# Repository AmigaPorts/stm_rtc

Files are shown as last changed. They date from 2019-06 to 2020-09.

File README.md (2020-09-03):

# STM32 emulator of msm6264b RTC for Amiga computers

This project aims to implement RTC replacement for classic Amiga computers.
Target uC was chosen to be as cheap as possible, easily available & RoHS-friendly.
This project may work on other computers, but it's not guaranteed.

If you made it work for other machine with some fix or without it,
tell me so by creating an issue!

## Build and flash

To build firmware, you'll need STM32CubeMX installed to generate required HAL stuff.
This way you can also easily port this project to other chips.

- Delete `build` folder if present in main repo directory.
- Delete `makefile` if present in main repo directory.
  For some reason STM32CubeMX doesn't regenerate it each time.
- Open stm_rtc_yourPartName.ioc in STM32CubeMX, then click `GENERATE CODE` button.
- After that, simply use generated makefile by writing:

``` sh
make OPT="-Ofast -std=c11 -Wpedantic -frename-registers" DEBUG=0
```

If you're on Windows and have MinGW installed, you may use `mingw32-make` instead.
This should generate firmware in `./build/stm_rtc.bin`.
I've used following GCC version:

``` plain
> arm-none-eabi-gcc --version
arm-none-eabi-gcc (GNU Tools for ARM Embedded Processors) 5.4.1 20160919 (release) [ARM/embedded-5-branch revision 240496]
```

To flash firmware into your STM you'll need `stm32flash` tool installed.
Required pinout is as follows:

``` plain
PA14 (TX) - USB-UART RX
PA15 (RX) - USB-UART TX
BOOT0     - 3v3 during programming, GND when run
RES       - 3v3 via 10k or any other resistor
```

You may need to drive RES for a short time to GND to reset device before programming.

Connect UART-USB dongle to your PC and type:

``` sh
stm32flash -R -w ./build/stm_rtc_stm32f031k4u.bin COM5
# or
stm32flash -R -w ./build/stm_rtc_stm32f030c6t.bin COM5
```

Of course replace COM5 with name of correct serial port.
You may use Realterm, Cutecom or whatever serial monitor you prefer to list them.

## How it works

TBD

## License

See each file for details.

- All ST code is under STMicroelectronics's license.
- MSM RTC emulation code found in `msm_rtc.c` and `msm_rtc.h` is licensed under [Mozilla Public License 2.0](LICENSE).

## TODO

- write
- add pinout compatibility with smaller stm32f0 packages
- port to  STM32F031C6T6
- PCB
- switch to LL generation for less footprint?
- compat with latest arm gcc?
- stm32f030 power saving code for even cheaper device?

## This worked on QFP48

``` asm
 147              	.L5:
 148 001c 0B69     		ldr	r3, [r1, #16]
 149 001e 1340     		ands	r3, r2
 150 0020 FCD1     		bne	.L5
 151 0022 3869     		ldr	r0, [r7, #16]
 152 0024 050A     		lsrs	r5, r0, #8
 153 0026 3540     		ands	r5, r6
 154 0028 A800     		lsls	r0, r5, #2
 155 002a 6546     		mov	r5, ip
 156 002c 2858     		ldr	r0, [r5, r0]
 157 002e 4546     		mov	r5, r8
 158 0030 6061     		str	r0, [r4, #20]
 159 0032 2560     		str	r5, [r4]
 160 0034 2360     		str	r3, [r4]
 161 0036 F1E7     		b	.L5
```

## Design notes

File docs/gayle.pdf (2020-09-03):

## ’ Specification GAYLE

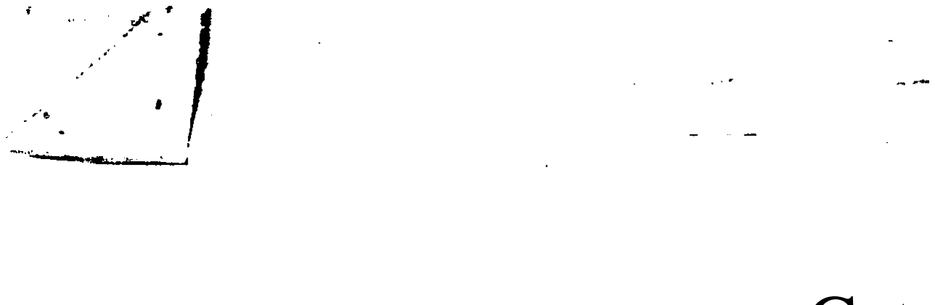
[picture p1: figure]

## Gate array for A30O/A500+ /w 0 /N APoo

1 .O DESCRIPTION

GAYLE is a gate array IC used in the A’300 and related systems. It is packaged in an 84 pin plastic leaded chip carrier (PLCC) whose pinout is shown below. GAYLE is capable of operating a 68000 based Amiga computer with theECS chipset, and a processor clock speed of 7.16 Mhz. GAYLE provides the following functions:

- Address decoding and timing for system ROM
- Address decoding and timing for optional flash ROM
- Address decoding and timing for chip RAM
- Address decoding and timing for chip registers
- Address decoding and timing for 8520’s (CIA’s)
- Address decoding and timing for real time clock (RTC)
- Address decoding and timing for Credit card connector
- Address decoding and timing for IDE hard disk drive
- Address decoding and timing for COM200020 ArcNet chip
- Generation of ECLK clock signal
- Data buffer control
- System RESET logic
- Floppy glue

[ Insert pinout here )

1.1 CONFIGURATION
The device shall be configured as a standard 54 pin plastic leaded chip carrier with external dimensions as shown in Figure XX-x. Refer to figure x-x for connection diagram.

1.2 SOURCES
Refer to Approved Vendor List.

1.3 PIN DESCRIPTIONS

1 | OUT
2 | OUT
3 | PWR
4 | TS
5 | OUT
6 | OUT
7 | OUT
8 | OUT
9 | OUT
10 | OUT
11 | OUT
12 | IN
13 | OUT
14 | OUT
15 | OUT
16 | OUT
17 | OUT
18 | OUT
19 | OUT
20 | PWR
21 | OUT
22 | IN
23 | IN
24 | PWR
25 | IN
26 | IN
27 | OC
28 | o c
29 | IN
30 | OUT
31 | OUT
32 | OUT
33 | IN
34 | IN
35 | IN
36 | IN
37 | TS
38 | IN
39 | o c
40 | o c
41 | IN
42 | IN
43 | IN
44 | IN
45 | PWR
46 | IN
47 | IN
48 | IN
49 | IN
50 | IN

PE12
PE5
Gndl
NOISE
CC-RESET
-CC-ENA
-CC-REG
-CC-CEL
-CC-CEU
E
FLAS H

### -mEJRQ

-DLCS(l)
DE-CW
-SPARE-CS
-INET-CS
-RTC-CS
-1OWR
-IORD
vcc 1
-ROMEN
C14M
CCK

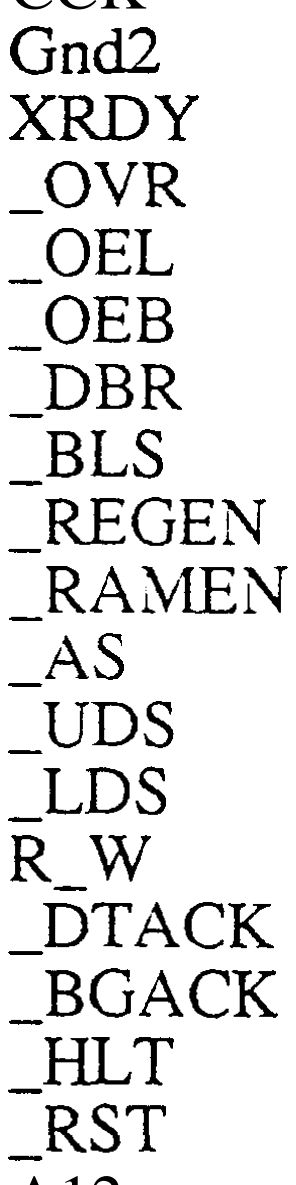
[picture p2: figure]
GIld.2 XRDY -0VR -0EL -0EB -DBR -BLS REGEN -RAMEN -AS -UDS -LDS R-W -DTACK -BGACK -HJJ- -RST

A12
Al3
A14
A15
Gnd3
A16
A17
Al8
A19
A20

Program Voltage 12V Enable Program Voltage 5V Enable
Ground
Digital Audio
Memory Card Reset
Memory Card Enable
Memory Card “Register” Space Memory Card Chip Enable Low byte Memory Card Chip Enable High byte CIA Phi 2
Flash Memory Chip Enable
IDE Drive Interrupt Request
IDE Drive Chip Select 1
IDE Drive Chip Select 2
Spare Chip Select
Network Controller Chip Select Real Time Clock Chip Select I/O Write Strobe
I/O Read Strobe
+5v
ROM Chip Enable
14 MHz C1ock In (master)
CCK Clock IN (sync)
Ground
Expansion Bus Wait
Expansion Bus Decode Override Chip->68000 Bus Buffer Enable 68000->Chip Bus Buffer Enable Agnus Chip Data Bus Required Agnus Chip Blitter Slowdown Agnus Chip Register Enable Agnus Chip RAM Enable
68000 Address Strobe
68000 Upper Data Strobe
68000 Lower Data Strobe
68000 Read/Write
68000 Data Transfer Acknowledge 68000 Bus Grand Acknowledge 68000 Halt
68000 Reset
68000 Address Bit 12
68000 Address Bit 13
68000 Address Bit 14
68000 Address Bit 15
Ground
68000 Address Bit 16
68000 Address Bit 17
68000 Address Bit 18
68000 Address Bit 19
68000 Address Bit 20
GAYLE Specification | July 10, 1991 | Page 2 of 17

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
A21 | 68000 Address Bit 21
A22 | 68000 Address Bit 22
A23 | 68000 Address Bit 23
D7 | 68000 Data Bit 7
D6 | 68000 Data Bit 6
D5 | 68000*Data Bit 5
D4 | 68000 Data Bit 4
D3 | 68000 Data Bit 3
D2 | 68000 Data Bit 2
Dl | 68000 Data Bit 1
DO | 68000 Data Bit 0
vcc2 | +5v
KBRESET DKWEB | Keyboard Reset In
DKWDB | Floppy Write Enable Out
Gnd4 | Floppy Write Data Out
| Ground
MTRON MTRX | Floppy Motor On Out
DKW E | Floppy Motor Out
-DKW-D | Floppy Write Enable In
MTR | Floppy Write Data In
-SEL | Floppy Motor In
-ODD-CIA | Floppy Select In
-EVEN-CIA | CIA Odd Chip Select
| CIA Even Chip Select

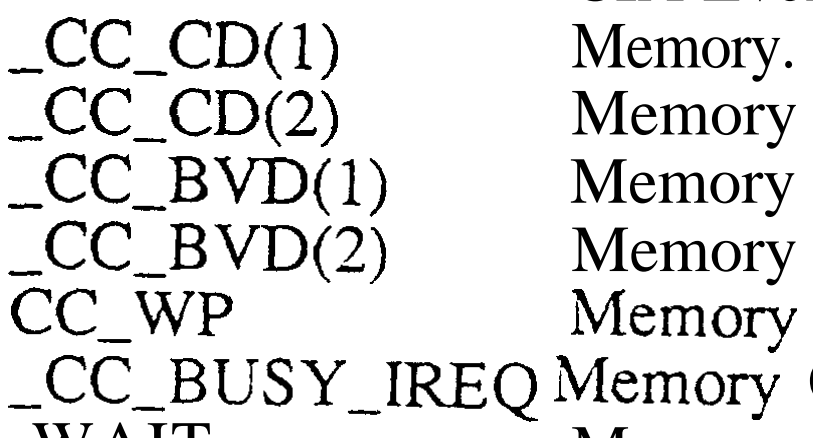
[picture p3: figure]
-CCCW) _Cccw2) -CCBWl) -CC_BVD(2) cc-WP

| Memory. Card Card Detect 1
| Memory Card Card Detect 2
| Memory Card Battery Voltage Detect 1
| Memory Card Battery Voltage Detect 2
| iMemory Card Write Protect
-CC-BUSY-IREQ LMemory Card Busy/Interrupt Request
-WAIT -BERR | Memory Card Wait
-INT6 | Bus Error Interrupt Request
-1NT2 | High Priority Interrupt Request
| Low Priority Interrupt Request
GAYLE Specification | Juiy 10, 1991 | Page 3 of 17

2.0 SYSTEM ROM

The onboard ROMs are selected in the address range from $OASOOOO to $OB7FFFF, $OEOOOOO to $OE7FFFF, and $OFSOOOO to $OFFFFFF. The ROMs are also selected in the range from $0000000 to $OlFFFFF when the internal overlay signal (OVL) is high (this allows the RESET vectors to be contained in the ROMs). The internal OVL signal becomes asserted at reset, and negates on the first write to CIA1 (address range of $BFDOOO to $BFDFFF.

2.1 ROM Timing

ROM timing is shown below:

## ROM Timing

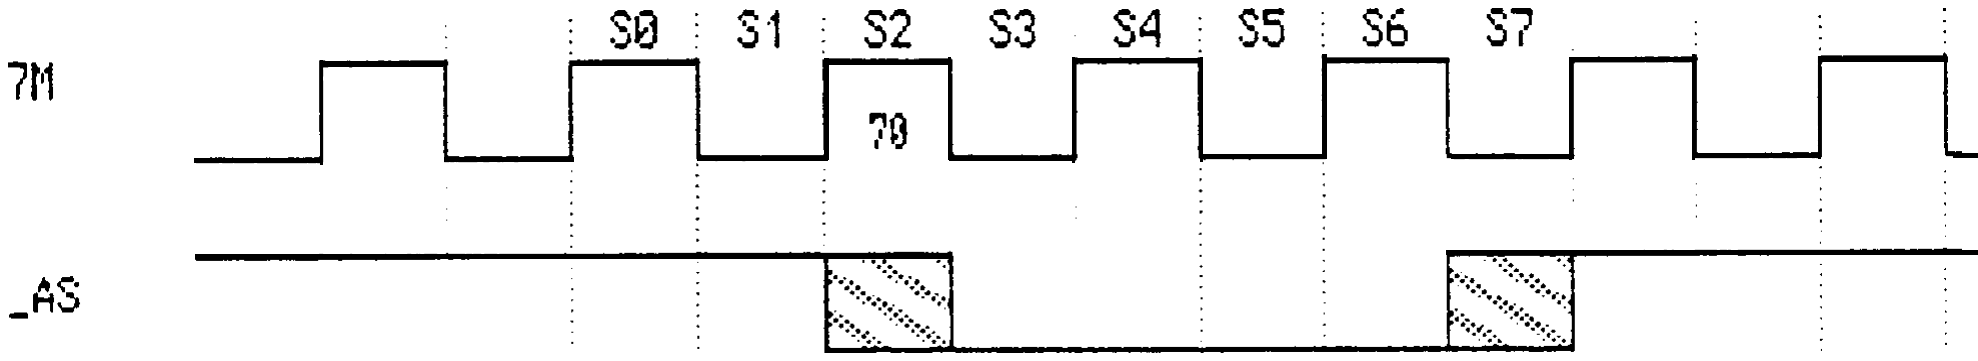
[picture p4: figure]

-ROM
I

JOH is a pure~address &code

: :

3.0 FLASH ROM
There is provision for an optional flash ROM device. The intent is that this is a possible replacement for a floppy disk drive in an extremely low end variant of the A300. The enable for the flash rom is called -FLASH-CE, and is active in the address range from $OAOOOOO to $OA7FFFF. This output is enabled when the proper data strobe is asserted, and the address is in range. Generation of -DTACK is identical to that for system ROa accesses.

3.0 CHIP RAM

Chip RAM cycles are generated during accesses to locations $0000000 to $0200000. When the internal OVL signal is asserted, ROM appears in this space instead of chip RAlM (see section on ROM for further information on OVL).

3.1 Chip RAM Timing

Timing for chip RAM cycles is given in the timing section of the Chip Register discussion (section 4.1). All timings given are equally valid for either chip registers or chip RAM.

4.0 CHIP REGISTERS

The chip registers are selected in the range from $ODFFOOO to $ODFFlFF. Chip registers show up in user and supervisor data space.

4.1 Chip RAM and Register Timing

Timing is given on the following page. Note that timimng for chip RAM accesses is identical. A wait state is inserted when the access is from a DMA device.

## Chip RAM and Register Timing

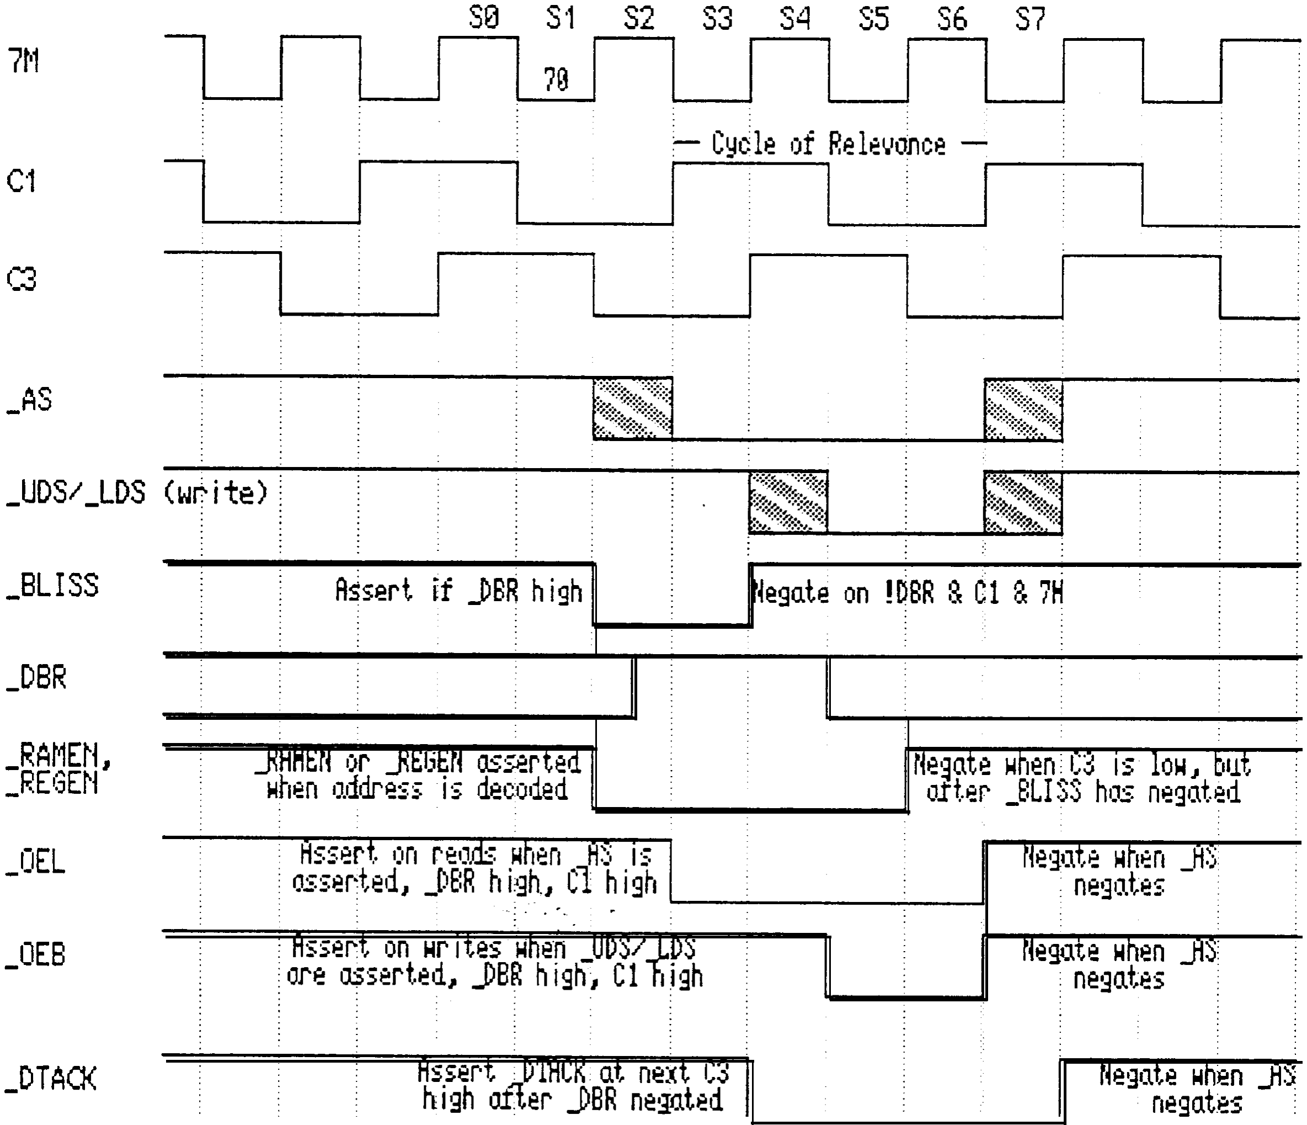
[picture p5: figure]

5.0 CIA’

The 8520 CIA’s are selected in the address range from $OBFOOOO to $OBFFFFF. ODD-CIA responds to addresses in this range in which address line 12 is low, with data appearing at odd addresses. The standard location to use in accesssing ODD-CIA is from $OBFEOOO to $OBFEFFF. EVEN-CIA responds to addresses from $OBFOOOO to $OBFFFFF in which address line 13 is low, with data appearing at even addresses. The standard location to use for accessing this CIA is from $OBFDOOO to $OBFDFFF.

5.1 CIA timing

GAYLE provides synchronization of the processor to CIA accesses as well as generation of the E clock signal. Timing is shown below:

## CIA Timing

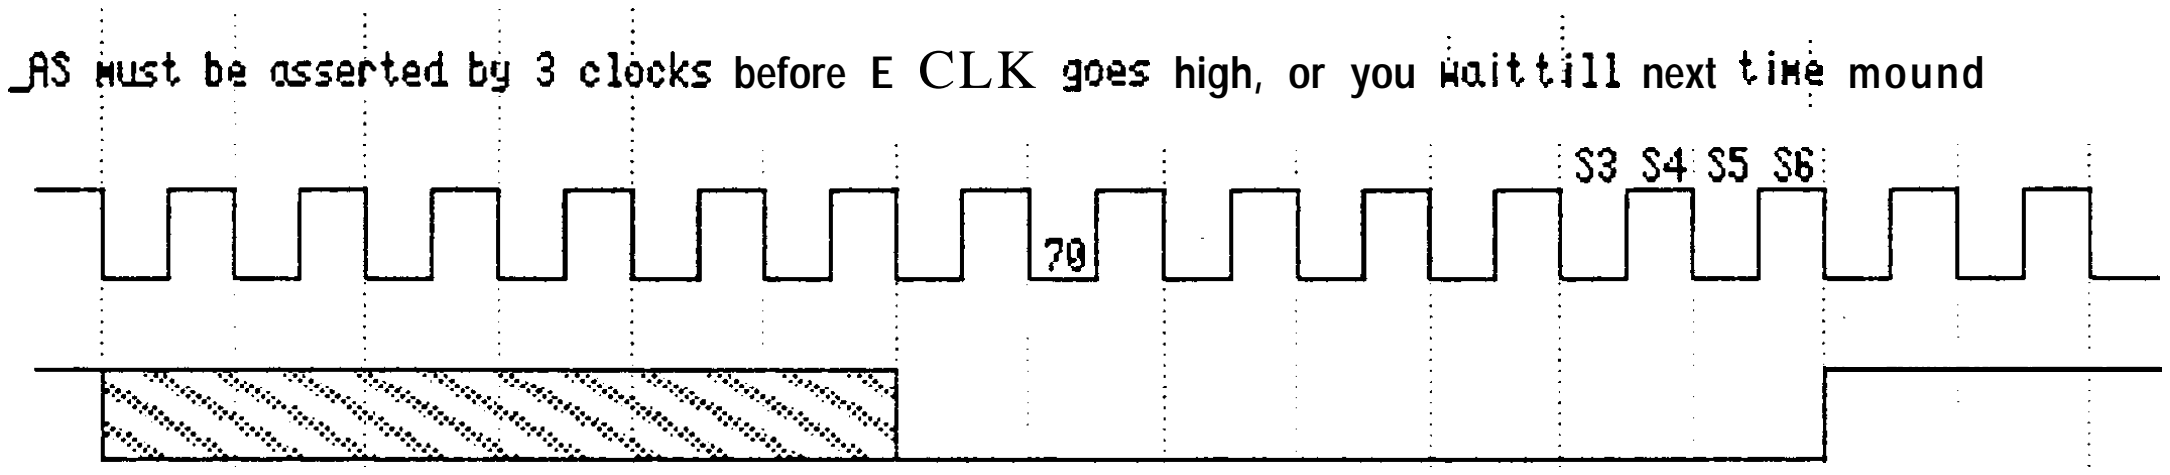
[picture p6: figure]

:ks before E CLK goes high, or you bait till next tin! mound

E CLK is lou foe E clocks . . . | then h igh for 4

Ass& 2 clocks before E CLK goes high

i JXACK ass&cd 2.5 clocks after E CLK h iih

6.0 REAL-TIME CLOCK

The real-time clock (RTC) is selected in the address range from $ODCOOOO to $ODCFFF. The RTC appears in both user and supervisor spaces.

6.1 RTC Timing

The real-time clock timing is based on the Ricoh RP5COl real-time clock chip. GAYLE’s timing to the RTC is shown below:

## Real Time Clock Timing

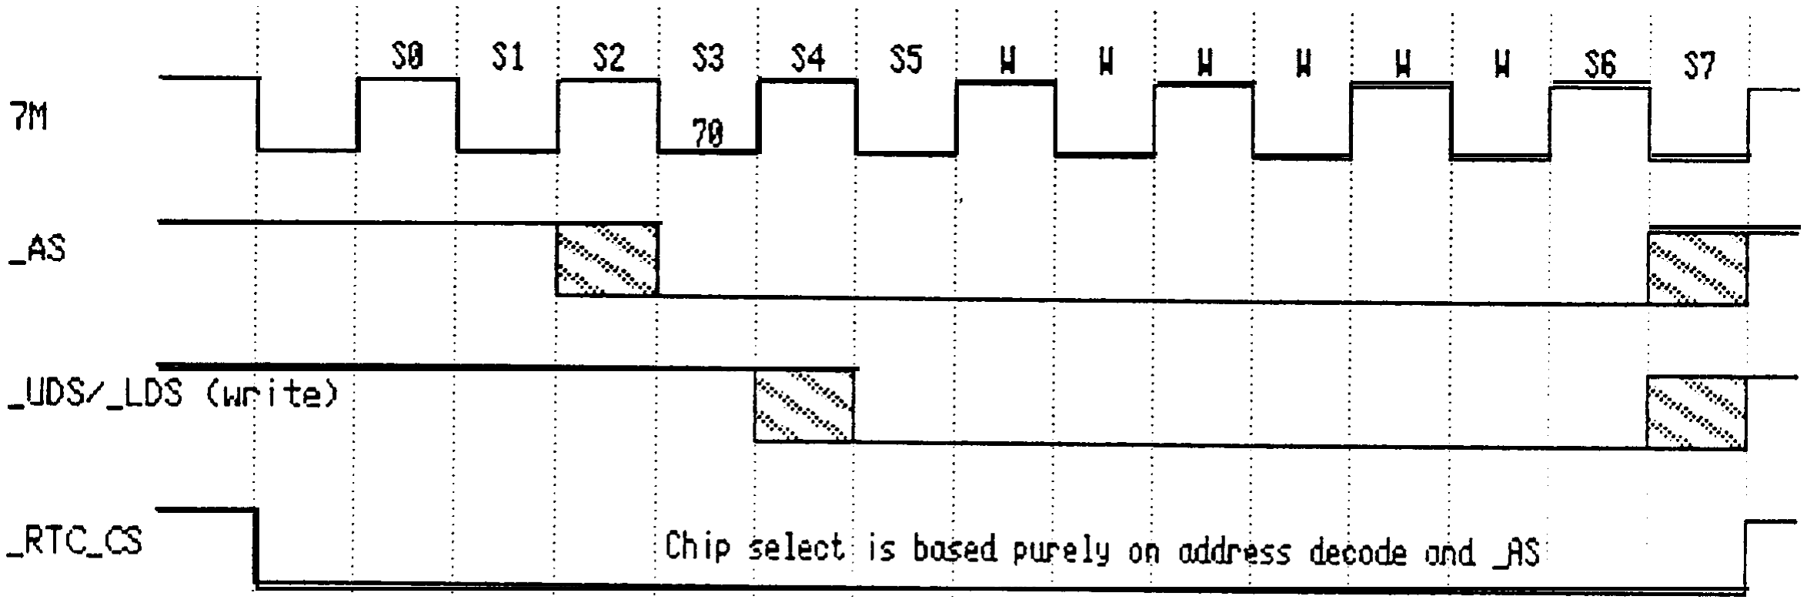
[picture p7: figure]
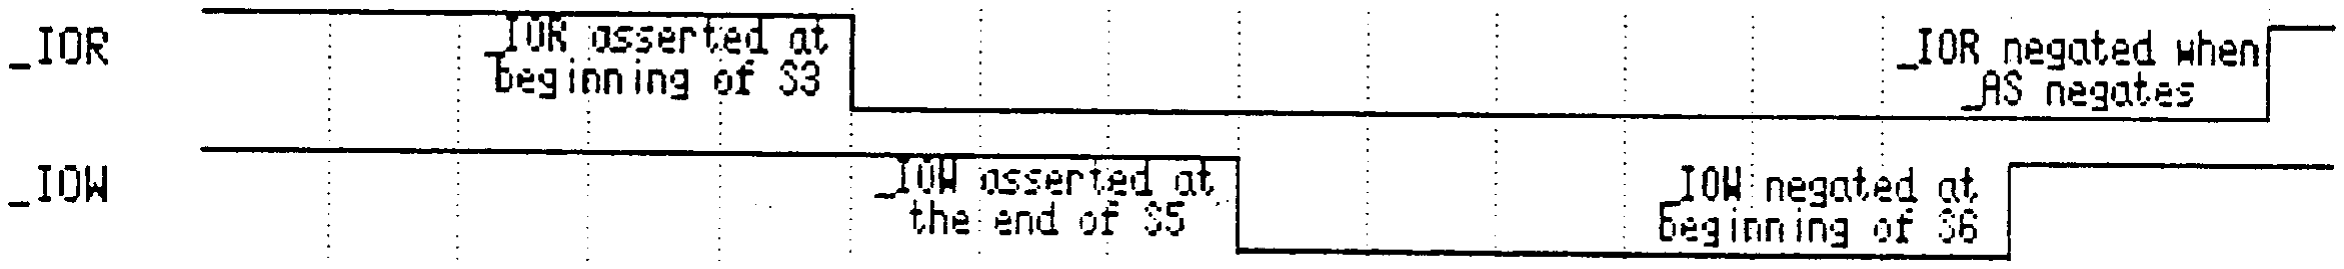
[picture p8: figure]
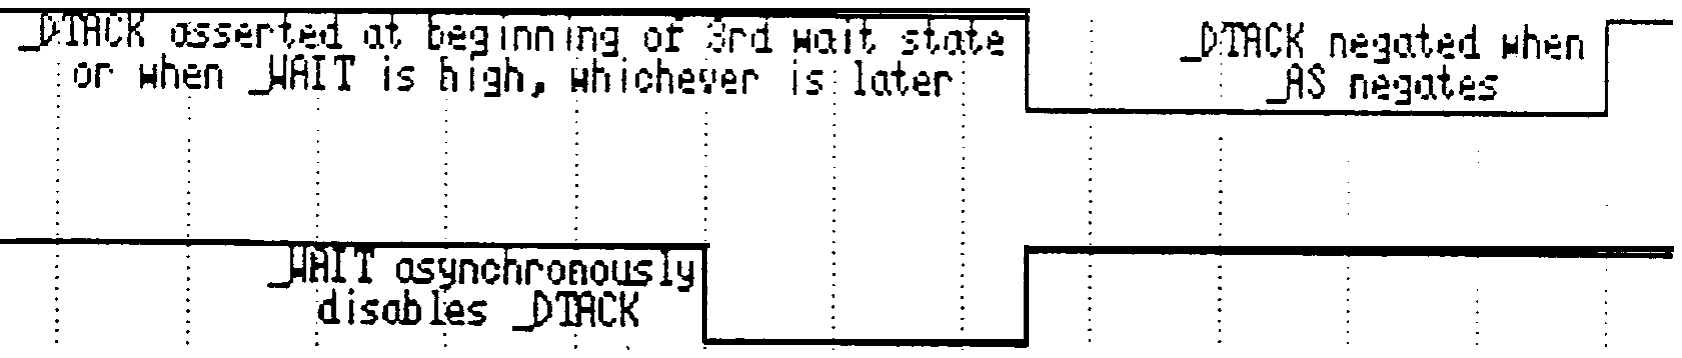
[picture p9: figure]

-WAIT

7.0 IDE HARD DRIVE

The IDE (AT) hard drive requires two mutually exclusive chip selects. Please see the chart below for address range in which each is active.
valid for IDE hard drives during these cycles.

The -1OW and -1OR signals have timing that is

Data register accesses CZ.P
control registers are

be performed faster than control register accesses. Accesses to the 1;dlled
accesses”.

“8 bit accesses” while those to the data register are called “16 bit Show: oelow is a table that gives the chip select and access speed versus address range.

4u+ | Al3 Al 2
b | 0 | | Address Range
| | 0 | $ODAOOOO to SODAOFFF
0 | 0 | 1 | $ODAlOOO to $ODAiFFF
0 | 1 | 0 | $ODA2000 to $ODA2FFF
0 | 1 | 1 | $ODA3000 to $ODA3FFF
1 | 0 | X | $ODA4000 to $ODASFFF
1 | 1 | X | $ODA6000 to $ODA7FFF

7.1 IDE Timing

IDE timing is shown below:

Chip Select Speed
-cs 1 | 8 bit
-cs2 | 8 bit
-cs 1 | 16 bit
-cs2 | 16 bit
None | 8 bit
None | 16 bit

, -

-7.
I
c
,’
\

//

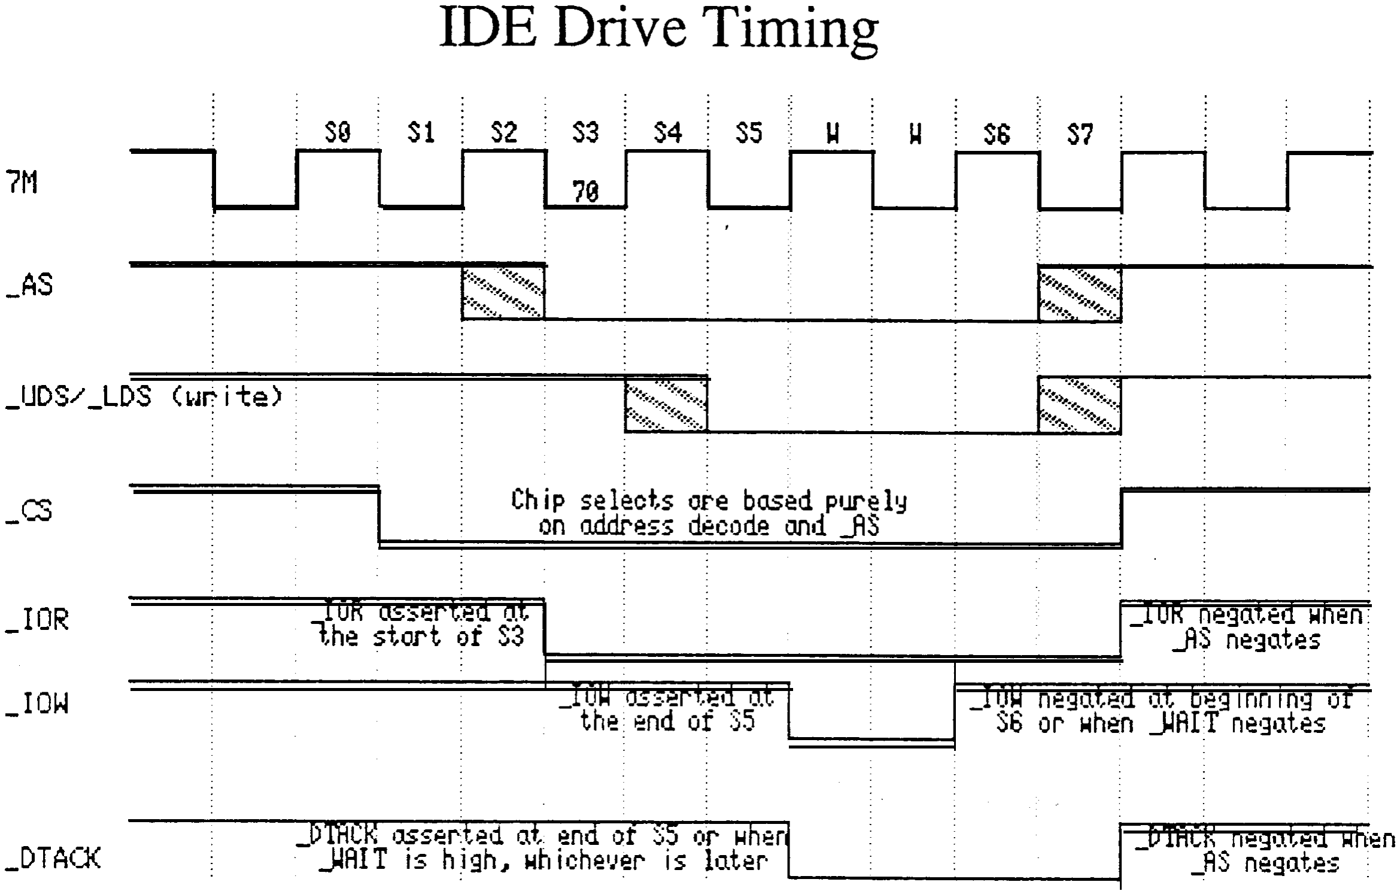
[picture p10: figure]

7.3 IDE Register Map

The disk drive address lines DAO, DAl, and DA2 are expected to be connected to processor address lines A2, A3, and A4 respectively.
memory map results:

When connected in this fashion, the following

Addr on AT
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
Valid Data
8 bits
8 bits
8 bits
8 bits
8 bits
8 bits
8 bits
8 bits
8 bits
16 bits

Read Function
Alternate Status
Drive address
Error Register
Sector Count
Sector Number
Cylinder Low
Cylinder High
Drive/Head
Status
Data

Write Function
‘Device Control
Not used
Features
Sector Count
Sector Number
Cylinder Low
Cylinder High
Drive/Head
Command
Data

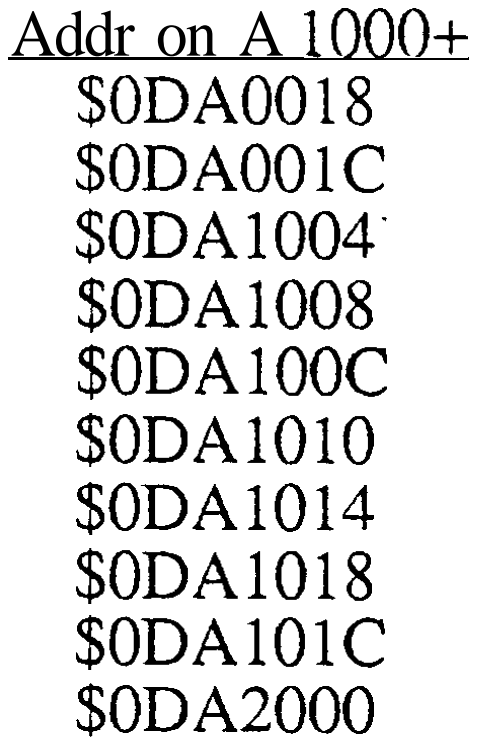
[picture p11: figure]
Addr on A lOOO+ $ODAOO18 $ODAOOlC $ODA1004‘ $ODAl008 $ODAlOOC $ODAlOlO $ODA1014 $ODA1018 $ODAlOlC $ODA2000

8.0 ARCNET

A chip select is provided for an SMC COM20020 ARCNET chip. The COM20020 interfaces directly to the processor for all other signals.

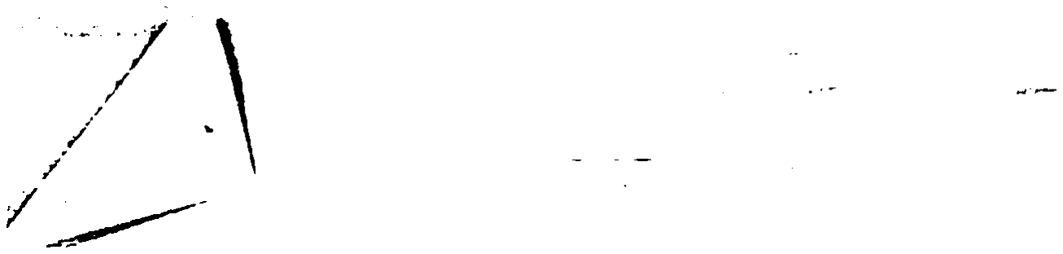
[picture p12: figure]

8.1 ArcNet Timing

Timing for the SMC COM20020 is shown below:

## ArcNet Timing

{Insert timing diagram here}

10.0 SYSTEM RESET LOGIC

The -KBRESET input drives the open collector outputs RESET an d -HALT low. No matter how short the pulse, GAYLE stretches the RESET and -HALT outputs to at least 560ns. When -RESETis driven low (either by GAYLE or externally), all internal states in GAYLE are reset, including the registers, which are all set to ‘0’.

11.0 SYSTEM CLOCKS

The system clocks expected by ANIMAL are shown below. Note that C3 is generated internally.

GAYLE Specification | July lo,1991 | Page 9 of 17

t

## Clocks

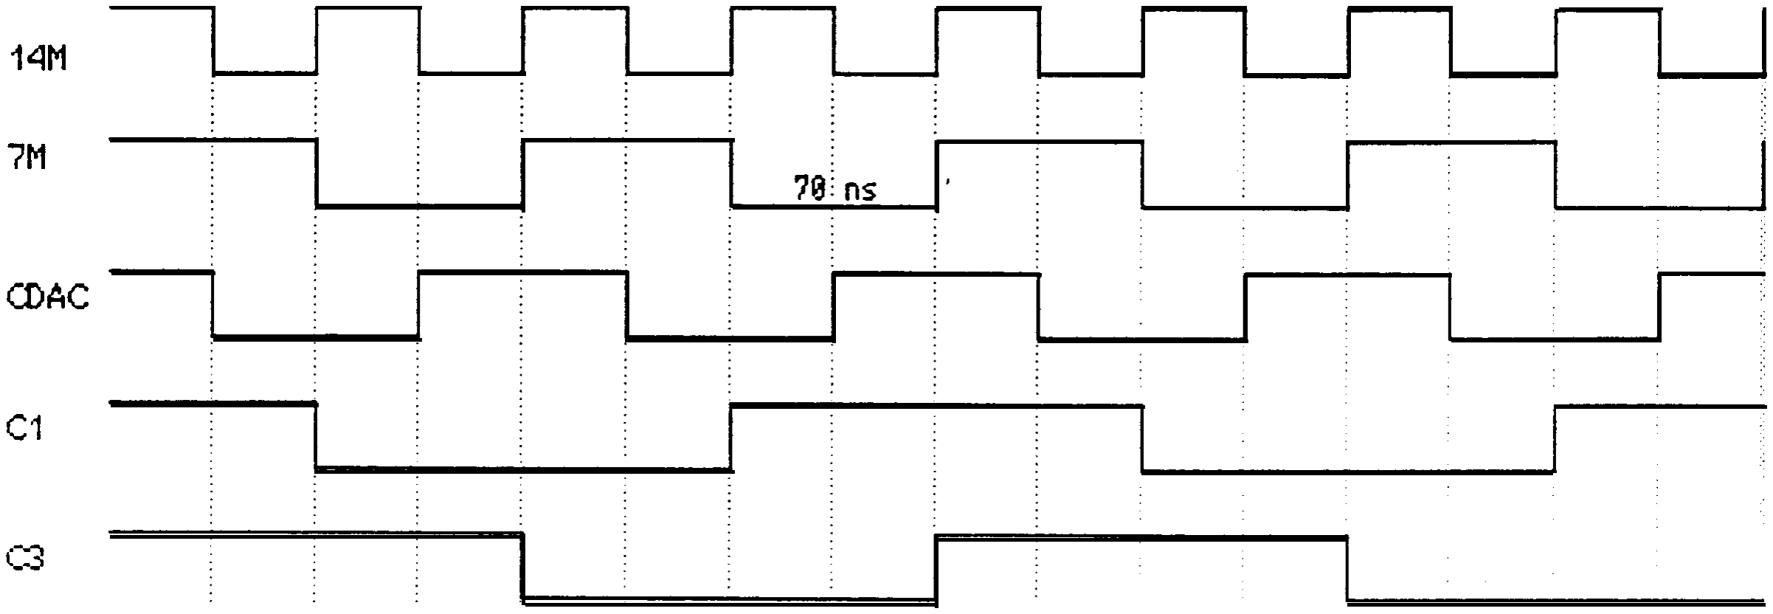
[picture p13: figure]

12.0 FLOPPY GLUE

The floppy signals MTRON, MTRX, DKWDB, and DKWEB are generated by GAYLE. All of these signals are open collector outputs.

MTRON is the signal that tells the floppy motor to turn on. It is the -MTR input latched by the -SEL input. MTRON is guaranteed negated when RESET is asserted.

MTRX is the signal that tells the floppy motor to do what, George? It follows the _ MTR input except during reset when it is guaranteed negated.

DKWDB is a buffered version of the -DKWD signal.

DKWEB follows DKWE, except it is negated during reset.

13.0 BUFFER CONTROL

SHould this be folded in with other sections, or is there something special to say, George?

14.0 DTACK GENERATION

Automatic generation of the 68000 cycle termination signal, DTACK, is provided. GAYLE decodes addresses to determine timing for the DTACK signal. Timing for DTACK is given in many of the individual sections of this specification, but for any address ranges not covered in other sections (such as expansion space), DTACK works as follows:

1. If -0VR or XRDY are not asserted, DTACK is generated at the beginning of S4, guaranteeing a 4 clock cycle.
2. When -0VR is asserted, the -DTACK output is tristated, allowing the device that asserted -0VR to generate its own -DTACK.
3. If XRDY is asserted in time, generation of -DTACK is held off until XRDY is negated.

14.1 DTACK Timing

Timing for DTACK is shown below:

## DTACK Timing

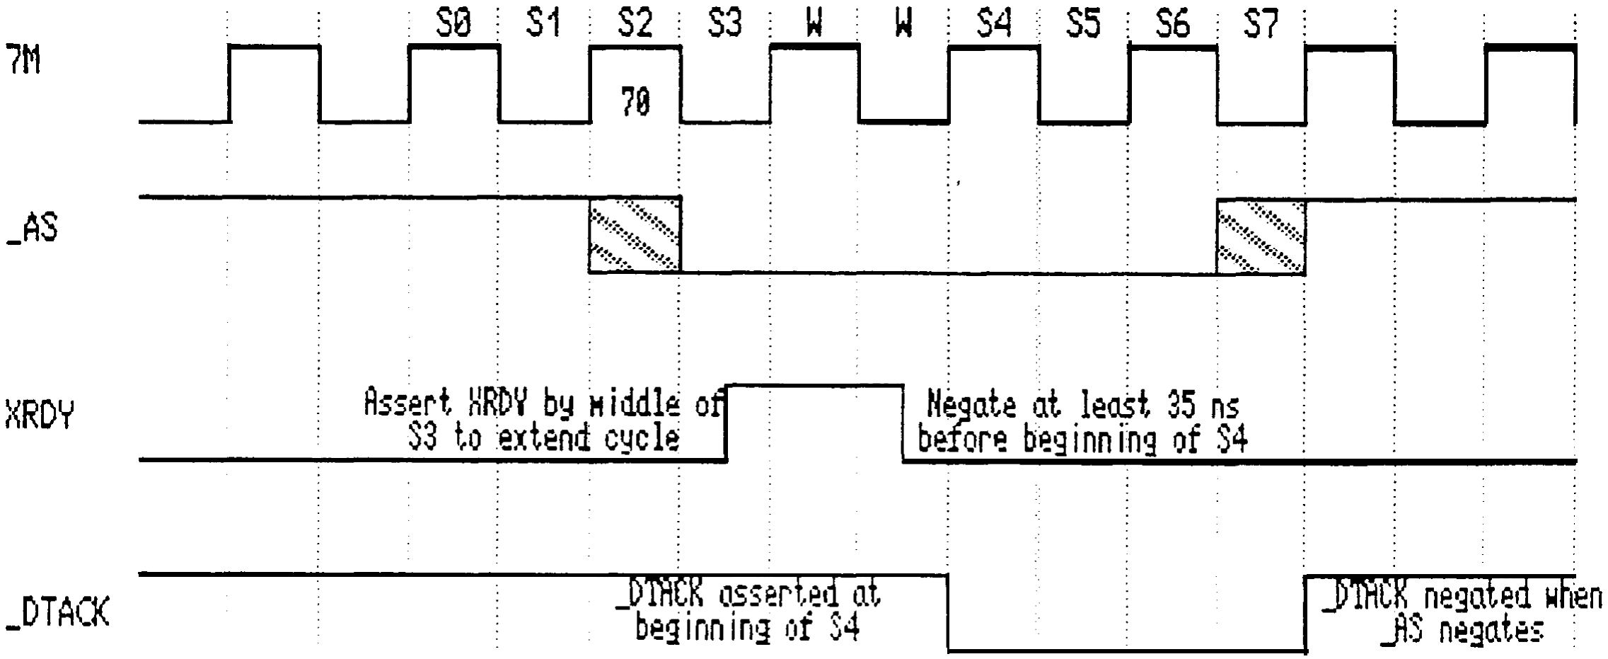
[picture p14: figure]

15.0 OVR AND XRDY SIGNALS

In addition to its function in overriding the generation of -DTACK, the -0VR signal can override address decoding in GAYLE. Thus it can be used to allow external devices to reside in address ranges that are normally reserved for motherboard devices, such as the credit card interface. Use of -0VR for this use basically requires that -0VR is asserted earlier than -AS. Address ranges where this is effective are shown below:

Address range
Normal cvcle tvDe
Flash ROM
Workbench ROM
Reserved for CDTV
External IDE drive
Reserved for DMA contr
System ROM
System | ROM | .

Cycle type with OVR
zorro II
zorro II
ZOITO II
Zorro II
ZOITO II
zorro II
zorro II

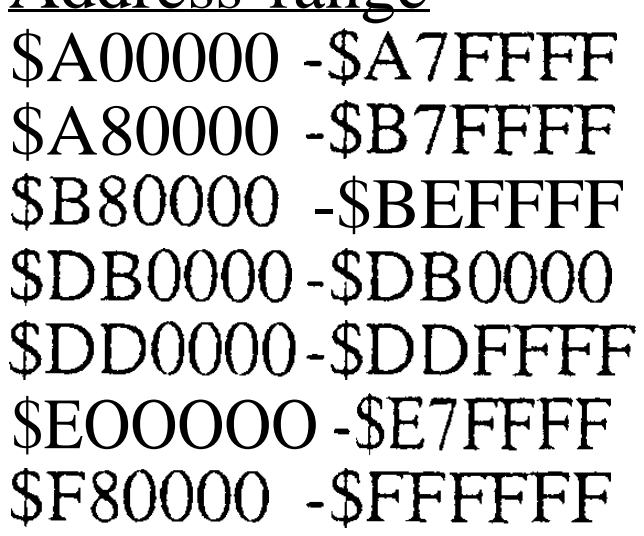
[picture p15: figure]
$A00000 -$A7FFFF $A80000 -$B7FFFF $BSOOOO -$BEFFFF $DBOOOO -$DBOOOO $DDOOOO-$DDFFFF $EOOOOO -$E7FFFF $FSOOOO -$FFFFFF

Any address ranges where -0VR is legal, use of the XRDY signal to extend the cycle is also legal. Other address ranges ignore the XRDY signal.

16.0 CREDIT CARD INTERFACE

GAYLE includes a complete interface to the industry standard PCMCIA cartridge. Limited support of hot insertion and removal is included. GAYLE supports three different kinds of credit card cycles:

- Credit card memory cycles
- Credit card attribute memory cycles
- Credit card I/O cycles

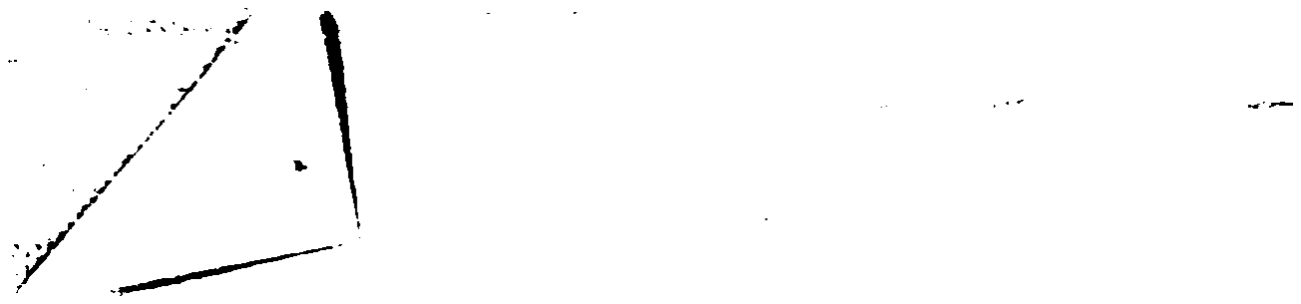
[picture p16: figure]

16.1 Credit card memory cycles

These cycles are active during accesses of address $4000’00 to $8FFFFF while a credit card is inserted. Accesses from $400000 to $7FFFFF are to the credit card main memory. Accesses from $8000000 to $8FFFFF are to credit card attribute memory. Both types of cycles are identical, except credit card attribute cycles assert -CC-REG and -CC-ENA, while main memory cycles just assert -CC-EINA. This represents 4 MB of directly accessable main memory address space. The full 64MB of defined address space may be reached using the page registers in GAYLE. Currently GAYLE does not actually support these, but future versions may very well do so.

-^

16.2 Credit card memory cycle timing

## Credit Card Memory Cycle Timing

33 Sl | s2 | 53 | 54 | 5.5 | $6 | ST
31 | 78

-as

,UDS-LDS ( WT? i te >
:
,CC,ENA/-REG is | Ch ip ielect.; are based purely: on address deco&
: | and:JS

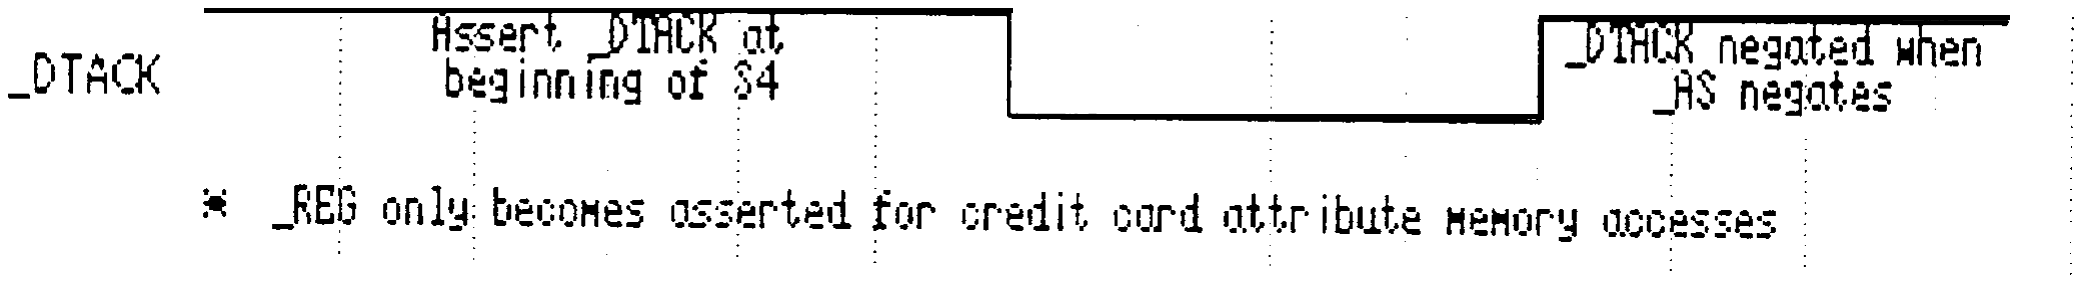
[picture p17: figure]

16.3 Credit card I/O cycles

Credit card I/O cycles occur during accesses to $900000 to $9FFFFF while a credit card is inserted.

16.4 Credit card I/O timing

Timing for credit card I/O cycles is shown below:

## Credit Card I/O Cycle Timing

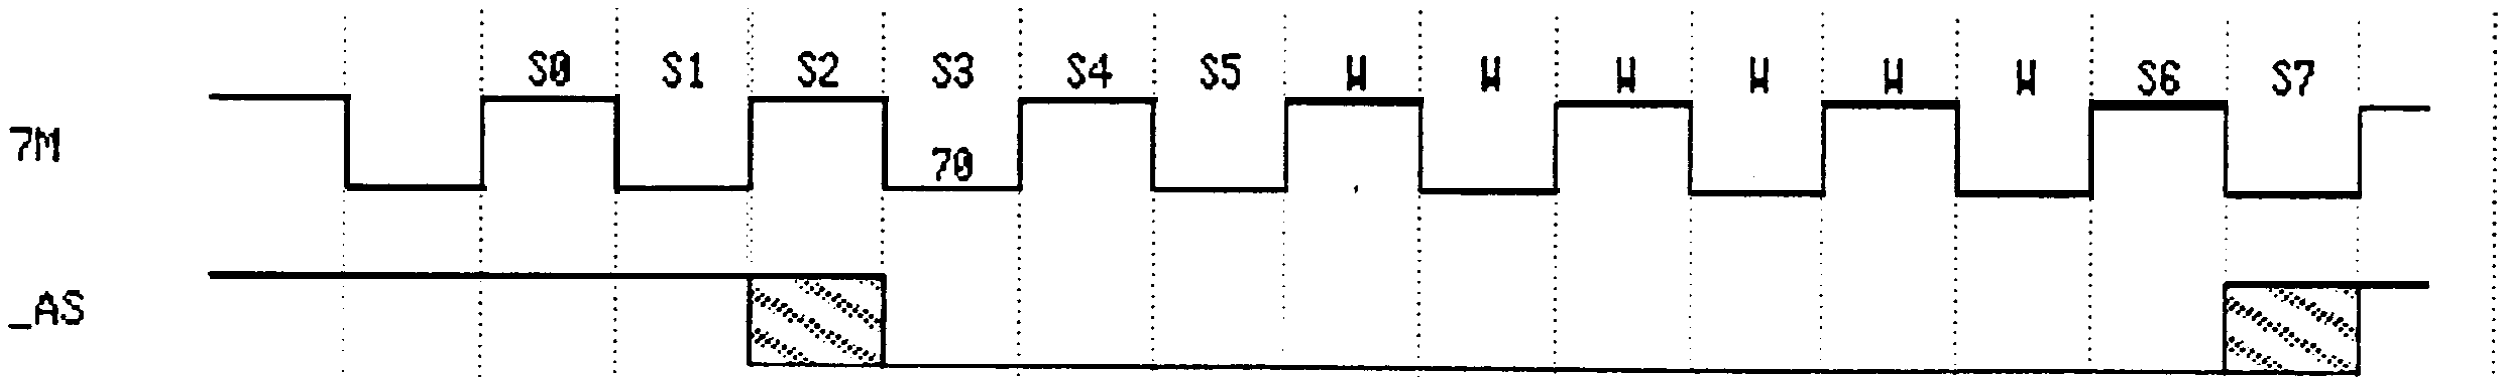
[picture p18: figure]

,UDS/,LDS (write>

,cc,REG

,IOR

Ch ip select is bused PM& ly on dress &code and JIS

JTACK

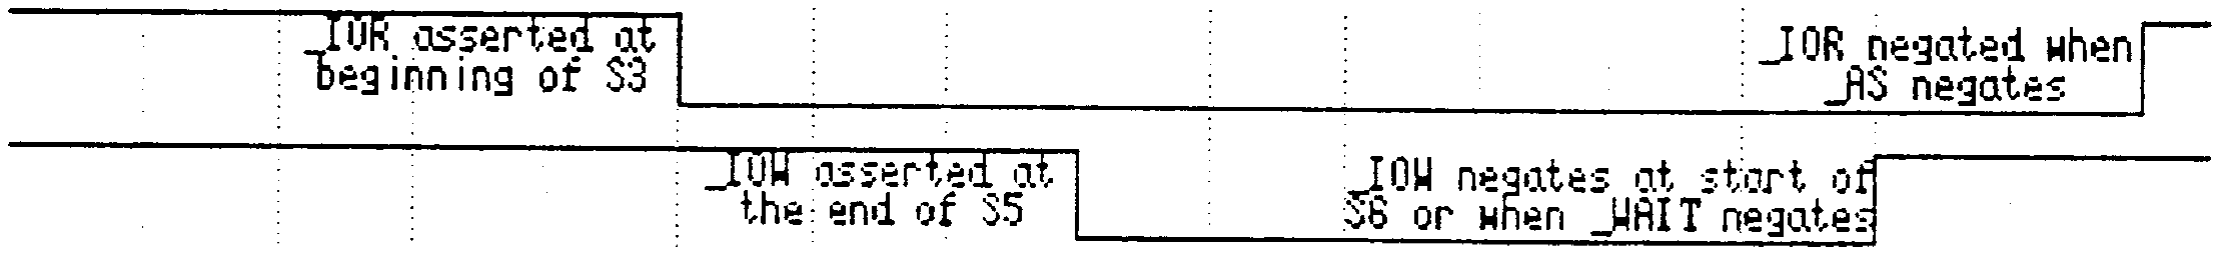
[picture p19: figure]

L OHS&- t:!,er clt kg Inning or 3rd mit stute
or when JUAIT is h Iqh, wh ichew is luter | F;p

TFICK nequted
H en JSS neg&s
-WAIT | i

17.0 Test Mode

If -0VR is asserted at the rising edge of -KBRESET, a test mode is entered in which the E clock state counters reset to a known condition.

18.0 SPARE chip select

A spare chip select is provided. It is asserted on any access to locations $DSOOOO to $D8FFFFF. Timing is similar to the ARCNET chip select.

19.0 GAYLE Registers

Four registers are included that facilitate support of the cartridge slot and IDE interrupt management. All registers are set to zero at reset time. These registers are shown on the following two pages:

Address SDA8000

1s

IDE int

StatUS

Rit 14

CC det
status
Flit 17 | Rit 17
BVD2/DA | BVDl/SC
status | status

Rit 11

WR enable
status

Rit II)
BSYJRQ
status

Rit 9

Dig Aud
enable

Rit 8

c c
disable
Bit 8: | Allows the software to disable the credit card interface altogether. Writing a value of ‘1’ disables
the credit card interface, ‘0’ allows it to become enabled (having no credit card installed also disables the interface. Disabling the credit card interface includes disabling address decoding for the credit card areas, makes the credit card inputs appear to be in the inactive state, and inhibits status change interrupts.
Bit 9: | Enable for the credit card digital audio output. Writing a ’ 1’ enables connecting the credit card
digital audio to the amiga audio and disables the BVD2 input to the interrupt request logic.
Bits 10-15: Each represent an external line. Reading any of these allows the software to determine the current state of the specified line. Writing a value of 1 to any of these bits allows the software to force GAYLE to behave as if the specified line is asserted (including returning a ‘1’ when this register is read). If the credit card is not inserted, or if the CC disable bit is asserted, the credit card lines will all appear to be negated, although any lines that the software has written a ‘1’ to will still read back as a ’ 1’. The external lines are as follows:
IDE int Interrupt output of the IDE drive; this bit is high whenever the IDE drive is generating an interrupt
CC det | Credit card detect: this bit is high whenever a credit card is present
BVD2/DA | Battery voltage detect 2 / Digital audio
BVDl/SC | Battery voltage detect 1 / Credit card (internal) status change
WR enable | Write enable; this bit is high when the credit card is write enabled. When low writes
are inhibited.
BSY/IRQ Credit card busy/Interrupt request

Address SDA9000

15

IDE int
change

Rit 14

CC det
change

Rit I’?

BVD2/DA
change

Rit I’?

BVDliSC
change

Rit 11

WR prot
change

Rit 10
BSYIIRQ
change

Rit 9

Reset on CC
status change

Rit 8

Berr on access
after stat change
Bit 8: | Allows the software to tell GAYLE to generate a reset whenever the credit card detect status line
has changed (i.e. the credit card has been inserted/removed).
Bit 9: | Causes a bus error to be generated on any access to the credit card area after the credit card detect
status line has changed.
Bits 10-15: Are the same signals as at address SDA8000, but the register at SDAAOOO tells you when any of these bits has changed value. The bit remains high (and the interrupt line remains active) until a ‘0’ is written to that bit. Writing a ‘1’ will cause a bit to be unchanged.

Address $DAAOOO

15

IDE int
int2 enable
Flit 14 | Rit 13
CC det | BVDUDA
int6 enable | int enable

Rit 13

BVDl/SC
int enable

Rit 11

WRenable
in2 enable

Rit 10
BSYKRQ
int enable

Rit 9

BVDIDAISC
int level
Rit 8 | t

BSY/IRQ int
level
Bit 8: | Sets the interrupt level that is generated when the BSY/IRQ (bit 10) status line changes state, a ‘1’
indicates in6t should be generated, a ‘0’ indicates int2,
Bit 9: | Similar to bit 8, except it is for the BVD (bits 12 and 13) inputs.
Bit 10: | Enables interrupt on status change of the BSY/IRQ line of the credit card interface. The interrupt
level that is generated is programmed by bit 8.
Bit 11: | Enables generation of an int2 on status change of the write enable line of the credit card interface.
Bit 12: | Enables interrupt on status change of the BVDl/SC line of the credit card interface. The interrupt
level that is generated is programmed by bit 9.
Bit 13: | Enables interrupt on status change of the BVD2/DA line of the credit card interface. The interrupt
level that is generated is programmed by bit 9. Bit 14: Enables generation of an int6 on status change of the credit card detect lines of the credit card interface.
Bit 15: | Enables generation of an int3 on status change of the interrupt line of the IDE interface.

Address SDABOOO

15

Page reg 25

Rit 14

Page reg 24

Rit 13

Page reg 23

Rit 12

Page reg 22

11

Slow mem

Rit 10

Delay write

Rit 9

Program 12v

Rit 8

Program 5V

Bit 8: | Enables the programmable 5 volt output. Setting both bit 8 and bit 9 together asserts the credit card reset signal. Note: Credit card not inserted or disabled forces the programmable 5 volt output to zero.
Bit 9: | Enabies the programmable 12 volt output. Setting both bit 8 and bit 9 together asserts the credit card reset signal. Note: Credit card not inserted or disabled forces the programmable 12 volt output to zero.
Bit 10: | Enables a mode where the credit card WAIT signal is looked at during writes (it is always looked at during reads). In a 68000 this necessitates insterting a wait state. When set to zero, zero wait state cycles are run.
Bit 11: | Enables 1.2 us memory cycles (instead of the normal 560ns).
Bits 12 -15: Are for the currently unimplemented credit card page registers. You can tell they are
| unimplemented because they do not read back what is written.
GAYLE Specification | July 10, 1991 | Page 15 of 17

17.0 MEMORY MAP

0000000 to OlFFFFF

0200000 to 03FFFFF

0400000 to 07FFFFF

0800000 to OWFFFF

0900000 to 09FFFFF

OAOOOOO to OA7FFFF

OA80000 to OB7FFFF

OBSOOOO to OBEFFFF

OBFOOOO to OBFFFFF

OCOOOOO to OD7FFFF

OD80000 to OD8FFFF

OD90000 to OD9FFFF

ODAOOOO to ODA3FFF

ODA4000to ODALCFFFF

ODA8000to ODAFFFF

ODBOOOO to ODBFFFF

ODCOOOO to ODCFFFF

ODD0000 to ODDFFFF

ODE0000 to ODEFFFF

ODFOOOO to ODFFFFF

OE00000 to OE7FFFF

OE80000 to OEFFFFF

OF00000 to OF7FFFF

OF80000 to OFFFFFF

2MB

2MB

4MB

1MB

1MB

512 KB

1 1MB

448 KB

64 KB

1.5 MB

64 KB

64 KB

16KB

16 KB

32 KB

64 KB

64 KB

64 KB

64 KB

64 KB

512 KB

512 KB

512 KB

512 KB

Chip RAM (or system ROM in overlay)

Zorro II expansion space

Credit Card memory if CC present (211 otherwise)

Credit Card attributes if CC present (211 otherwise)

Credit Card I/O if CC present (211 otherwise)

Flash ROM

System ROM selected (optional workbench ROM)

Not used (Reserved for CDTV)

CIA’s (See section on CIA’s for more detail)

COO000 Memory

SPARE chip select

ARCNET chip select

IDE drive (see section on IDE for register map)

IDE reserved

Credit Card & IDE configuration registers

Not used (Reserved for external IDE)

Real time clock

RESERVED for DMA controller

Not Used

Chip registers (shadowed 8 times)

System ROM (1st half if 1MB ROM)

Configuration and I/O card space

Cartridge space

System ROM (2nd half if 1MB ROM)

GAYLE Specification | July 10, 1991 | Page 16 of 17

18.0 PHYSICAL REQUIREMENTS

18.1 Marking

Devices shall be marked with Commodore part number plus a copyright notice as follows:
1990 CBM.

18.2 Packaging

The interconnected circuitry shall be contained in a standard 84-pin plastic leaded chip carrier with exterminal dimensions shown in Figure XX-X.

19.0 PROCESS QUALIFICATION TESTS

Integrated circuitrs supplied to the requirements of this specification shall meet the requiremtnes of Engineering Policy No. 1.02.008, whatever that is. Supporting doucmentation shall be supplied by vendor upon request.

19.1 Environmental test conditions

Devices shall comply with blah blah blah

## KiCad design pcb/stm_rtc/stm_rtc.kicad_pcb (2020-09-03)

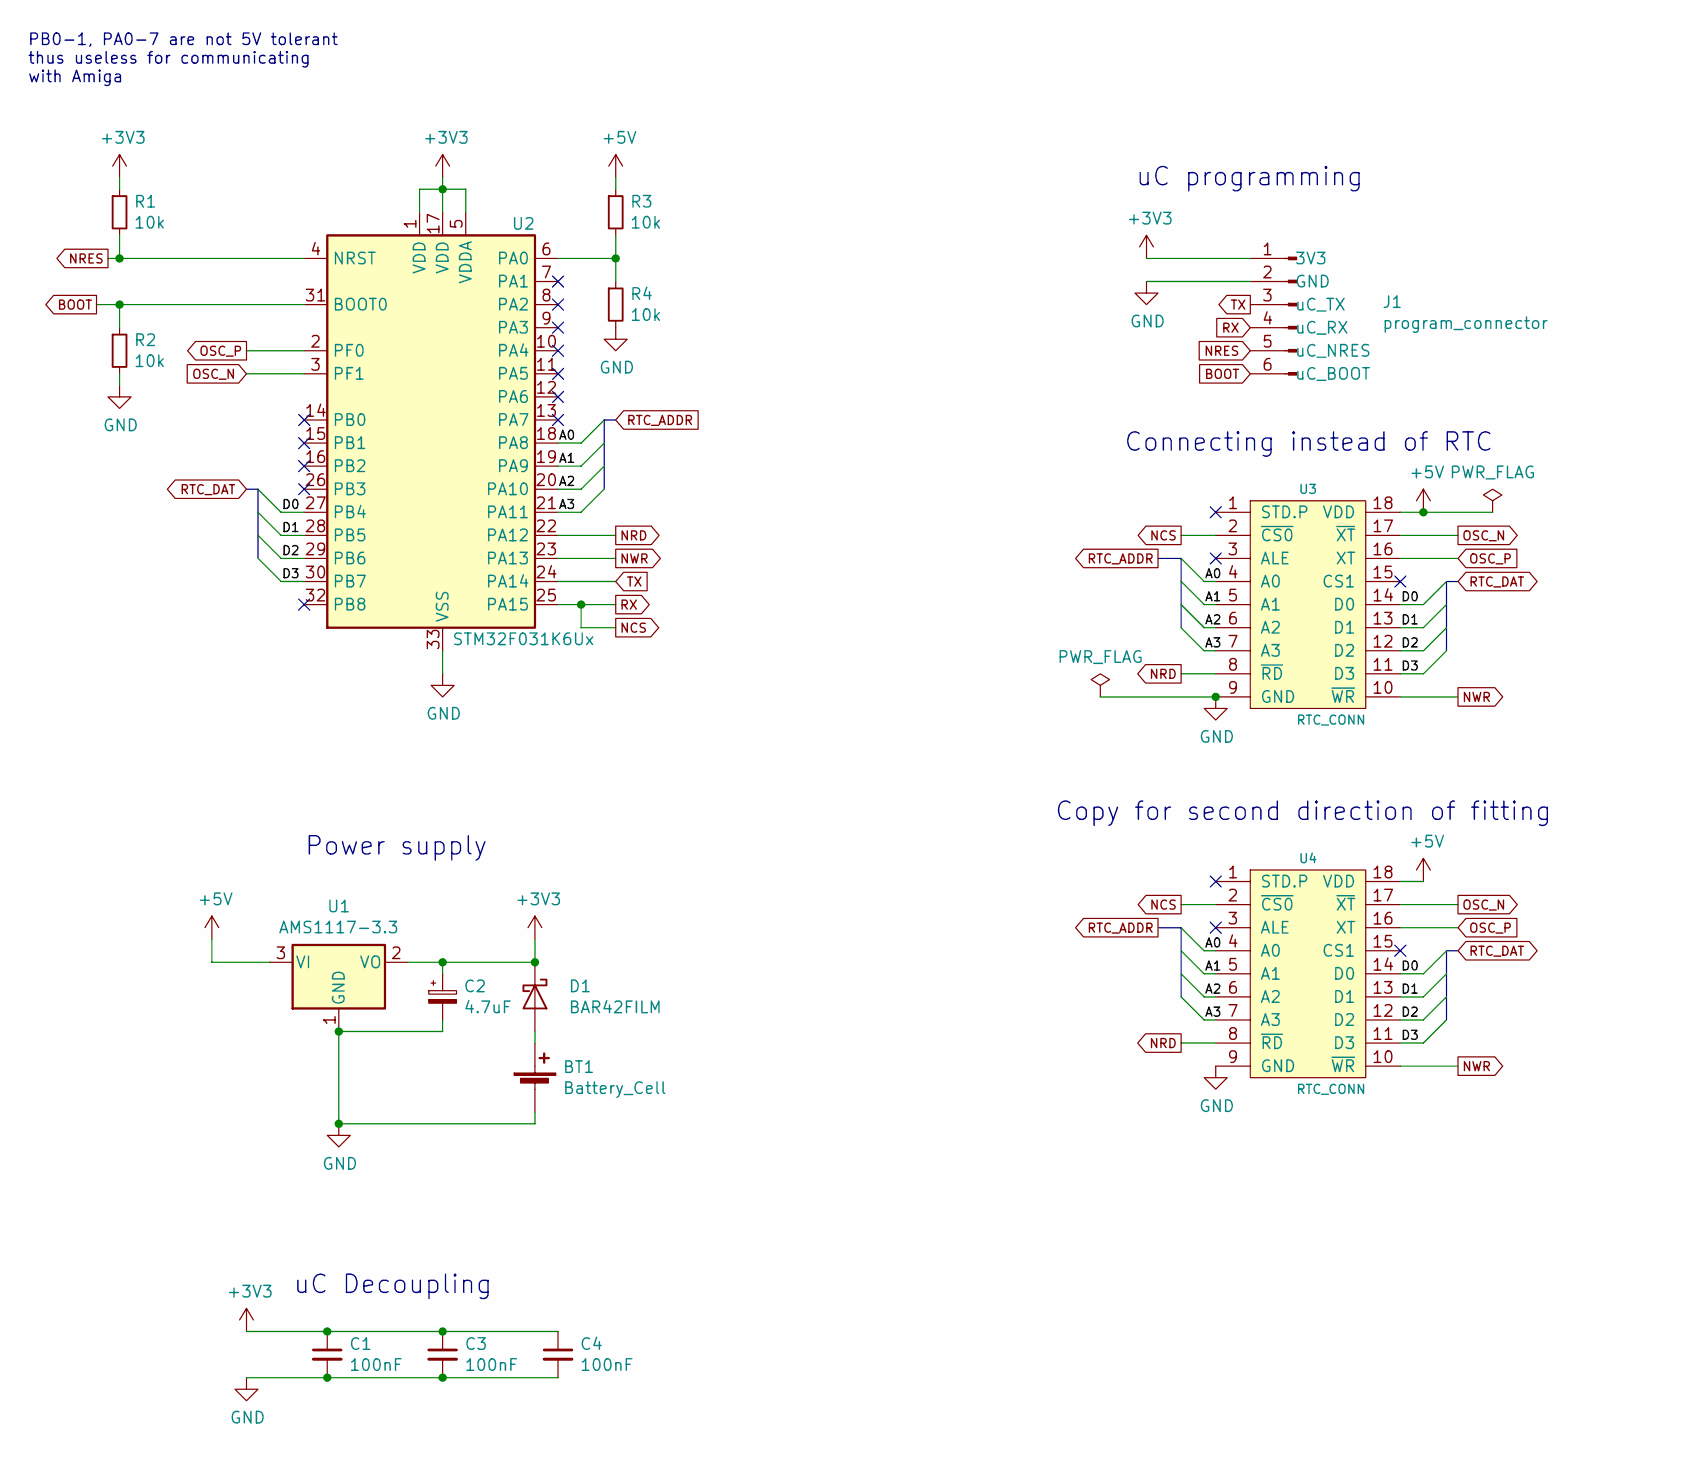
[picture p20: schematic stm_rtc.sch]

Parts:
BT1: Battery_Cell; BatteryHolder_Keystone_106_1x20mm
C1, C3, C4: 100nF; C_0805_2012Metric_Pad1.15x1.40mm_HandSolder
C2: 4.7uF; C_0805_2012Metric_Pad1.15x1.40mm_HandSolder
D1: BAR42FILM; SOT-23
J1: program_connector; PinHeader_1x06_P2.54mm_Vertical
R1, R2, R3, R4: 10k; R_0805_2012Metric_Pad1.15x1.40mm_HandSolder
U1: AMS1117-3.3; SOT-223-3_TabPin2
U2: STM32F031K6Ux; QFN-32-1EP_5x5mm_P0.5mm_EP3.45x3.45mm
U3, U4: RTC_CONN; DIP-18_W7.62mm

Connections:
+3V3: C1.1, C2.1, C3.1, C4.1, D1.3 (K), J1.1 (3V3), R1.1, U1.2 (VO), U2.1 (VDD), U2.5 (VDDA), U2.17 (VDD)
+5V: R3.1, U1.3 (VI), U3.18 (VDD), U4.18 (VDD)
/A0: U2.18 (PA8), U3.4 (A0), U4.4 (A0)
/A1: U2.19 (PA9), U3.5 (A1), U4.5 (A1)
/A2: U2.20 (PA10), U3.6 (A2), U4.6 (A2)
/A3: U2.21 (PA11), U3.7 (A3), U4.7 (A3)
/D0: U2.27 (PB4), U3.14 (D0), U4.14 (D0)
/D1: U2.28 (PB5), U3.13 (D1), U4.13 (D1)
/D2: U2.29 (PB6), U3.12 (D2), U4.12 (D2)
/D3: U2.30 (PB7), U3.11 (D3), U4.11 (D3)
BOOT: J1.6 (uC_BOOT), R2.1, U2.31 (BOOT0)
GND: BT1.2 (-), C1.2, C2.2, C3.2, C4.2, J1.2 (GND), R2.2, R4.2, U1.1 (GND), U2.33 (VSS), U3.9 (GND), U4.9 (GND)
NCS: J1.4 (uC_RX), U2.25 (PA15), U3.2 (~CS0), U4.2 (~CS0)
NRD: U2.22 (PA12), U3.8 (~RD), U4.8 (~RD)
NRES: J1.5 (uC_NRES), R1.2, U2.4 (NRST)
NWR: U2.23 (PA13), U3.10 (~WR), U4.10 (~WR)
unnamed: BT1.1 (+), D1.1 (A)
unnamed: R3.2, R4.1, U2.6 (PA0)
OSC_N: U2.3 (PF1), U3.17 (~XT), U4.17 (~XT)
OSC_P: U2.2 (PF0), U3.16 (XT), U4.16 (XT)
TX: J1.3 (uC_TX), U2.24 (PA14)

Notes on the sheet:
uC Decoupling
PB0-1, PA0-7 are not 5V tolerant thus useless for communicating with Amiga
Power supply
uC programming
Connecting instead of RTC
Copy for second direction of fitting

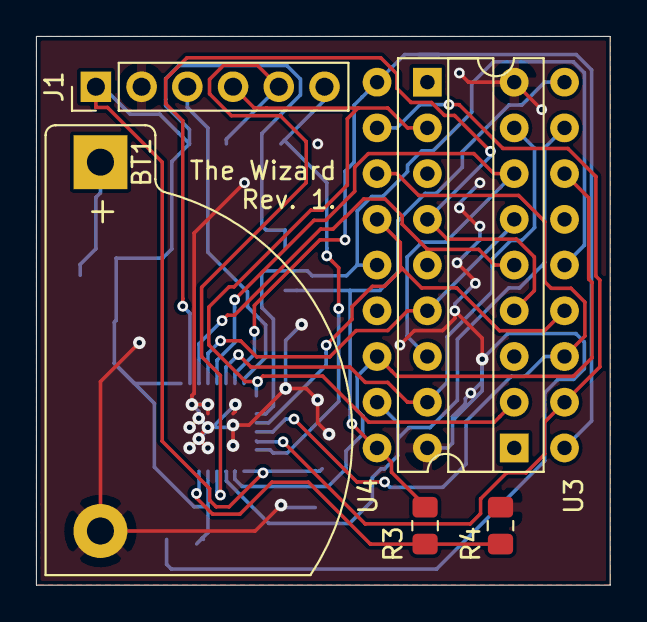
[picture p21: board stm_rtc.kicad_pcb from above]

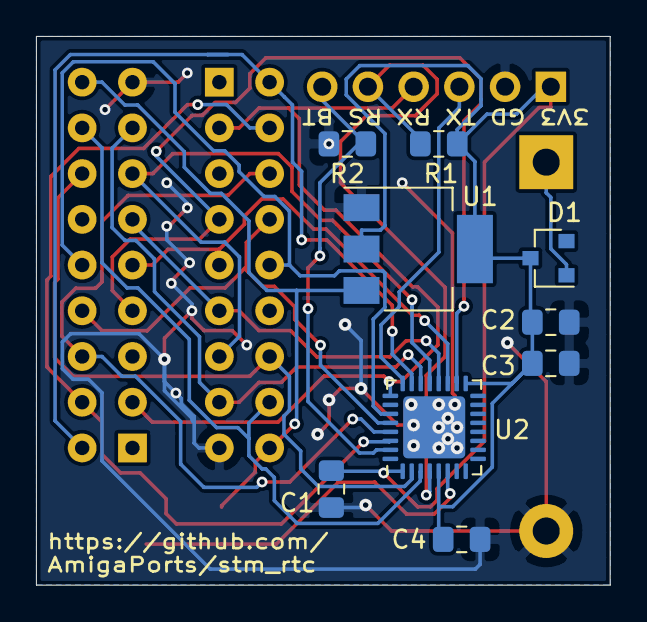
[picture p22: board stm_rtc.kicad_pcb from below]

Board: 2 copper layers, 31.9 x 30.5 mm, 15 parts (9 on the bottom side), 21 nets.

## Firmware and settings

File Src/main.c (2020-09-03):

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
/* Includes ------------------------------------------------------------------*/
#include "main.h"

/* USER CODE BEGIN Includes */
#include <string.h>
#include <errno.h>
#include <sys/unistd.h> // STDOUT_FILENO, STDERR_FILENO
#include "msm_rtc.h"
/* USER CODE END Includes */

RTC_HandleTypeDef hrtc;

UART_HandleTypeDef huart1;

void SystemClock_Config(void);
static void MX_GPIO_Init(void);
static void MX_RTC_Init(void);
static void MX_USART1_UART_Init(void);
/* USER CODE BEGIN 0 */

// Reimplementation of stdlib's _write for retargeting printf into UART 1
// https://electronics.stackexchange.com/questions/206113/
int _write(int file, char *data, int len) {
	if ((file != STDOUT_FILENO) && (file != STDERR_FILENO)) {
		errno = EBADF;
		return -1;
	}

	HAL_StatusTypeDef status = HAL_UART_Transmit(
		&huart1, (uint8_t*)data, len, HAL_MAX_DELAY
	);

	// return # of bytes written - as best we can tell
	return (status == HAL_OK ? len : 0);
}

/* USER CODE END 0 */

/**
  * @brief  The application entry point.
  * @retval int
  */
int main(void)
{
  /* MCU Configuration--------------------------------------------------------*/

  /* Reset of all peripherals, Initializes the Flash interface and the Systick. */
  HAL_Init();

  /* Configure the system clock */
  SystemClock_Config();

  /* Initialize all configured peripherals */
  MX_GPIO_Init();
  MX_RTC_Init();
  MX_USART1_UART_Init();
  /* USER CODE BEGIN 2 */

	msmRtcInit();

  /* USER CODE END 2 */

  /* Infinite loop */
  /* USER CODE BEGIN WHILE */
  while (1)
  {
    /* USER CODE END WHILE */

    /* USER CODE BEGIN 3 */
		msmRtcLoop();
	}
  /* USER CODE END 3 */
}

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


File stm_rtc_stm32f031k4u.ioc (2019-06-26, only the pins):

Mcu.UserName=STM32F031K4Ux
PA10.GPIO_Label=A2
PA10.Signal=GPIO_Input
PA11.GPIO_Label=A3
PA11.Signal=GPIO_Input
PA12.GPIO_Label=NRD
PA12.Signal=GPIO_Input
PA13.GPIO_Label=NWR
PA13.Signal=GPIO_Input
PA14.Signal=USART1_TX
PA15.GPIO_Label=NCS
PA15.Signal=GPIO_Input
PA3.Signal=USART1_RX
PA8.GPIO_Label=A0
PA8.Signal=GPIO_Input
PA9.GPIO_Label=A1
PA9.Signal=GPIO_Input
PB4.GPIO_Label=D0
PB4.Signal=GPIO_Input
PB5.GPIO_Label=D1
PB5.Signal=GPIO_Input
PB6.GPIO_Label=D2
PB6.Signal=GPIO_Input
PB7.GPIO_Label=D3
PB7.Signal=GPIO_Input

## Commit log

2019-06-25 pcb rev1
    [stm_rtc.kicad_pcb, stm_rtc.sch]
2019-06-26 ported to STM32F031K4U
2020-09-03 added stm32g0 config
2020-09-03 stm32g0 tweaks, further migrating code

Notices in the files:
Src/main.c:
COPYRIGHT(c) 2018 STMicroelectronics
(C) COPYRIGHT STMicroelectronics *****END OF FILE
